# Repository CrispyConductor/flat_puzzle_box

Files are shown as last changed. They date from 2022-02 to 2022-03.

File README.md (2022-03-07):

# 3D Printed Flat Puzzle Box

This is a 3d printed box that opens when its sliders are set to the correct code.  It's written for OpenSCAD and is designed to be customizable and flexible, supporting a wide range of sizes, dimensions, scales, and other options.

## Components

- Inner Box: The inside part of the box that comes out when opened.
- Outer Box A & B: The outside portion of the box prints in 2 parts that need to be glued together; the main body, and the top.
- Sliders: One slider for each position in the code.  Each slider is specific to its digit/letter/whatever.  You only need to print the sliders needed for your code.

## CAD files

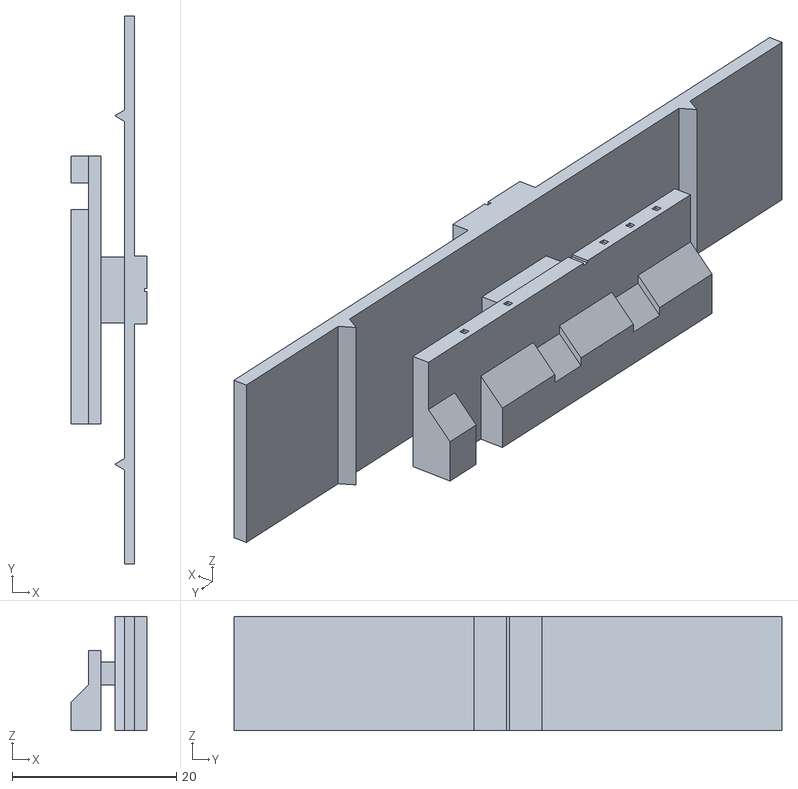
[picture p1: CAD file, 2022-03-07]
example_stls/slider_8.stl
9.20 x 66.7 x 13.9

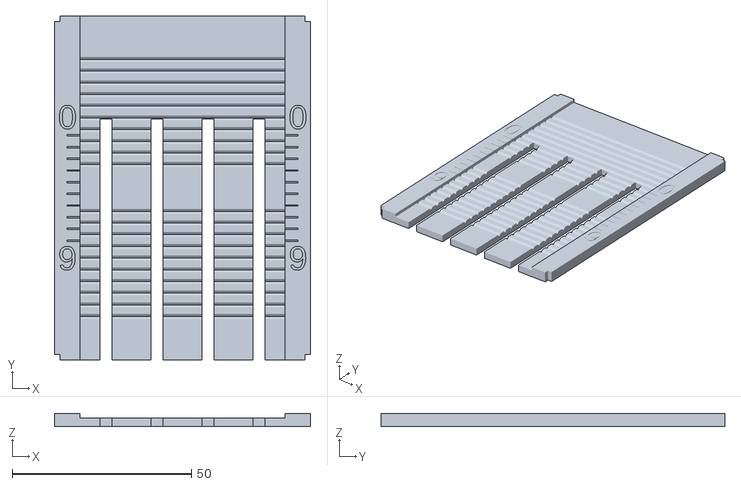
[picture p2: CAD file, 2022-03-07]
example_stls/outer_box_B.stl
71.5 x 96.0 x 3.60

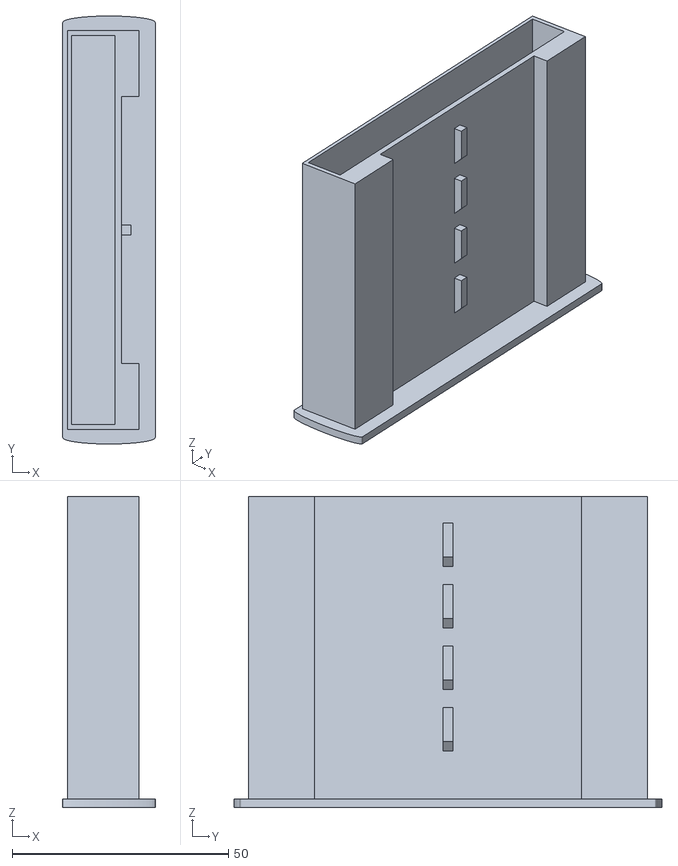
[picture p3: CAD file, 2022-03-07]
example_stls/inner_box.stl
21.4 x 99.0 x 72.0

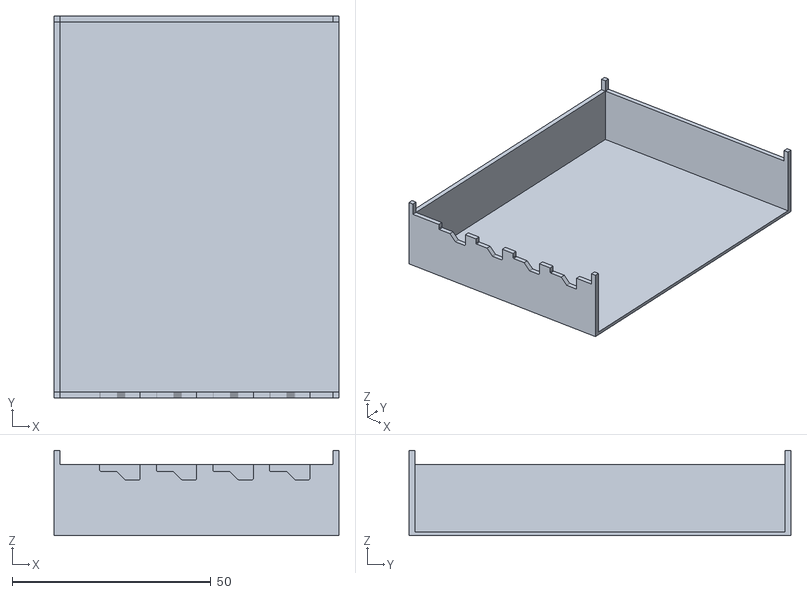
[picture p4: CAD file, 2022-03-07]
example_stls/outer_box_A.stl
71.5 x 96.0 x 21.4

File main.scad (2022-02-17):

/* [Which Part] */

// Part to render
part = "InnerBoxPrint"; // [ InnerBoxPrint, OuterBoxPrint1, OuterBoxPrint2, SliderPrint, InnerBox, OuterBox, Slider ]

// Used for Slider part only.  Which slider number this is, 0-indexed.
slider_num = 0;

// Used for Slider part only.  Which position number this slider is coded for, 0-indexed.
position_num = 0;


/* [Main] */

// The string of position labels to use for the primary scale.
primary_scale = "0123456789";

// The string of position labels to use for the secondary scale, or undef if only one scale.
secondary_scale = undef;

// Which scale (0 for primary, 1 for secondary) to use for each slider.  This also defines the number of sliders.
slider_scales = [ 0, 0, 0, 0, 0 ];

// Inner dimensions of box cavity: width, depth, height; when drawer is facing to the right
inner_size = [ 50, 60, 5 ];


/* [Misc] */

// Depth of the detent hole
detent_height = 0.7;

// Maximum length of the detent lever arm (from the slider connector piece to the detent peg).  A smaller length may be chosen if possible to fit in two detent pegs.
detent_lever_arm_length_max = 20.0;

// Minimum length of the detent lever arm.
detent_lever_arm_length_min = 10.0;

// Defines the width of the margins on the +x and -x side of the box top, as a fraction of the box width
outer_box_top_margin_frac = 0.1;

// The width of the separating walls between sliders, as a fraction of the total width of the slider space
slider_separator_width_frac = 0.03;

// Minimum absolute width of separating walls between sliders.  If the calculated width is below the minimum, separating walls will be removed entirely.
min_between_slider_wall_width = 2;

// The length of the connecting piece of the slider, as a fraction of the outer box depth.  Larger values are stronger but reduce travel length and compress symbols.  The multiplier is arbitrarily chosen.  This is the main parameter to tweak for altering travel distance vs slider stabilization in this dimension.
slider_connector_length_frac = 0.083;

// The width of the connecting piece of the slider, as a fraction of the space between the centers of 2 adjacent sliders.  This also determines slot width.
slider_connector_width_frac = 0.2;

// Amount the handle on the slider protrudes
slider_handle_height = 1.5;

// The depth (along the length of the slider) of space that the handle takes up, as a fraction of the length of the slider's top wing
slider_handle_depth_frac = 0.125;

// Minimum opening span of the slider gates.  This ensures proper printing and proper clearances, but if the scale is too compact, may cause adjacent slider positions to also allow through the pins.
min_gate_opening = 2.5;

// The width of the slider's gate fin, as a fraction of the width of the right half of the bottom wing.
slider_gate_width_frac = 0.5;


/* [Marks] */
// Depth of scale markings
scale_mark_height = 0.3;

// Width/thickness of scale marking lines
scale_mark_width = 0.4;

// Type of primary scale
primary_scale_mark_type = "compact"; // [ ticks, full, compact ]

// Type of secondary scale
secondary_scale_mark_type = "compact"; // [ ticks, full, compact ]

// Used to guess how much space a label will take up.  This should be the ratio of character width to character height, approximately.  Adjust this if scale labels are intersecing the edges.
font_width_to_height_ratio = 0.95;

// Multiplier to turn a bounding box height into an approximate font point size
font_height_to_point_size_multiplier = 0.9;


/* [Minor Dims] */

// Thickness of inner box walls
inner_box_wall_thick = 1.2;

// Thickness of inner box bottom
inner_box_bottom_thick = 0.95;

// Thickness of inner box top
inner_box_top_thick = 1.5;

// Thickness of the backplate/handle on the end of the inner box
inner_box_end_plate_thick = 2;

// Distance the inner box handles protrudes to either side of the outer box when closed
inner_box_side_handle_protrusion = 1.5;

// Minimum thickness at thinnest point of outer box top
outer_box_min_top_thick = 1.7;

// Outer box wall thicknesses
outer_box_wall_thick = 1.5;

// Outer box bottom thickness
outer_box_bottom_thick = 0.95;

// Thickess of the slider top wing plate/detent arm
slider_top_wing_thick = 1.2;

// Thickness of the bottom wing; thicker values are stiffer but bulkier
slider_bottom_wing_thick = 1.5;

// The fraction of the gate hole width/depth that should be indented for false gates
false_gate_indent_width_frac = 0.2;

// The width and depth of the binary pips that mark each slider with its position
binary_pips_mark_depth = 0.2;

// Width of binary pips
binary_pips_mark_width = 0.5;

/* [Clearances] */

// The amount of sliding play/clearance the inner box has inside the outer box in the Y dimension
inner_box_play_y = 0.6;

// Minimum height of intersection between pins on inner box and gate fins on the sliders.
gate_pin_contact_height = 1.5;

// Amount of play/clearance between slider wings and the slot it rides in.
slider_wing_play_z = 0.5;

// The minimum amount of clearance between the gates on the bottom of the sliders, and the top of the inner box.
gate_inner_box_top_clearance_z = 0.2;

// Minimum clearance between the tops of the pins on the inner box and the bottoms of the slider wings
pin_wing_clearance_z = 0.2;

// The clearance between the tops of the rails on the inner box and the bottom of the outer box lid.
inner_box_top_rail_play_z = 0.3;

// Clearance between each slider and either the adjacent slider or the slot wall in the X dimension
slider_top_wing_clearance_x = 0.3;

// Amount of play the slider has in the X dimension
slider_play_x = 0.45;

// Extra clearance between bottom of slider gate and top of inner box, in addition to existing plays and clearances.
slider_gate_inner_box_top_clearance_extra = 0;

// Clearances around box front cutouts for inserting sliders
outer_box_front_slider_cutout_clearance = 0.2;

// Clearance between bottom wing of slider and the top rails in the first and last positions
bottom_wing_top_rail_clearance = 0.2;

// Amount of clearance in the X dimension between a pin and its gate when the box is closed.  This translates to slop in opening of the box while locked.
pin_gate_closed_clearance_x = 0.2;

// Amount of extra clearance between the back side of an inner box pin and the previous gate it runs next to.
pin_next_gate_closed_clearance_x = 0.2;

// Extra clearance (in addition to inner_box_play_y) between pins and gates in Y dimension
pin_gate_clearance_y_extra = 0.2;

// Distance to extend slot length by to give a more positive detent click
slot_end_extra_clearance_y = 0.55;




module FlatPuzzleBoxPart(
    /* OPTIONS TO SELECT WHAT PART TO MAKE */
    // Which part of the box to create.  Values are "InnerBox", "OuterBox", or "Slider" for the parts in their native orientations.  For the printable versions, use "InnerBoxPrint", "OuterBoxPrint1", "OuterBoxPrint2", or "SliderPrint".
    part,
    // Used for Slider part only.  Which slider number this is, 0-indexed.
    slider_num = 0,
    // Used for Slider part only.  Which position number this slider is coded for, 0-indexed.
    position_num = 0,

    /* PRIMARY OPTIONS */
    // The string of position labels to use for the primary scale.
    //primary_scale = "0123456789",
    primary_scale = "ABCDEFGHIJKLMNOPQRSTUVWXYZ",
    // The string of position labels to use for the secondary scale, or undef if only one scale.
    secondary_scale = undef,
    // Which scale (0 for primary, 1 for secondary) to use for each slider.  This also defines the number of sliders.
    slider_scales = [ 0, 0, 0, 0, 0 ],
    // Inner dimensions of box cavity: width, depth, height; when drawer is facing to the right
    inner_size = [ 50, 60, 5 ],
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

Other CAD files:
example_stls/slider_7.stl
example_stls/slider_2.stl
example_stls/slider_1.stl
example_stls/slider_0.stl
example_stls/slider_5.stl
example_stls/slider_3.stl
example_stls/slider_4.stl
example_stls/slider_9.stl
example_stls/slider_6.stl

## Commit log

2022-02-10 Define top margins
    [main.scad]
2022-02-10 More tweaks to clearances around sliders and walls and stuff
    [main.scad]
2022-02-10 Few adjustments before next test print
    [main.scad]
2022-02-10 False gates
    [main.scad]
2022-02-10 Adjustments after test print 3
    [main.scad]
2022-02-10 Scale markings
    [main.scad]
2022-02-10 Slider markings
    [main.scad]
2022-02-11 Minor changes after test print
    [main.scad]
2022-02-11 Cleanup: Remove commented code
    [main.scad]
2022-02-11 Adjust fake gate interval
    [main.scad]
2022-02-11 Slightly increase to box size, and to font ratio, for alpha
    [main.scad]
2022-02-12 Make some settings module parameters
    [main.scad]
2022-02-12 More stuff as module options
    [main.scad]
2022-02-12 Make customizerable
    [main.scad]
2022-02-12 Add python script
    [main.scad]
2022-02-12 Detent arm length params
    [main.scad]
2022-02-16 Relax some clearances
    [main.scad]
2022-02-17 Increase clearance
    [main.scad]
2022-03-07 Add example STLs
    [inner_box.stl, outer_box_A.stl, outer_box_B.stl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]
